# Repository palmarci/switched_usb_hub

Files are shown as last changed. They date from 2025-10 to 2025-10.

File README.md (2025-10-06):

# switched_usb_hub

a very cheap and basic switched usb 2.0 hub design based on:

- SL2.1A USB 4 way hub IC
- CH340C USB - serial adapter
- STM32F030F4Px microcontroller

the mcu talks with the PC over UART and toggles some FETs using GPIOs. nothing fancy.

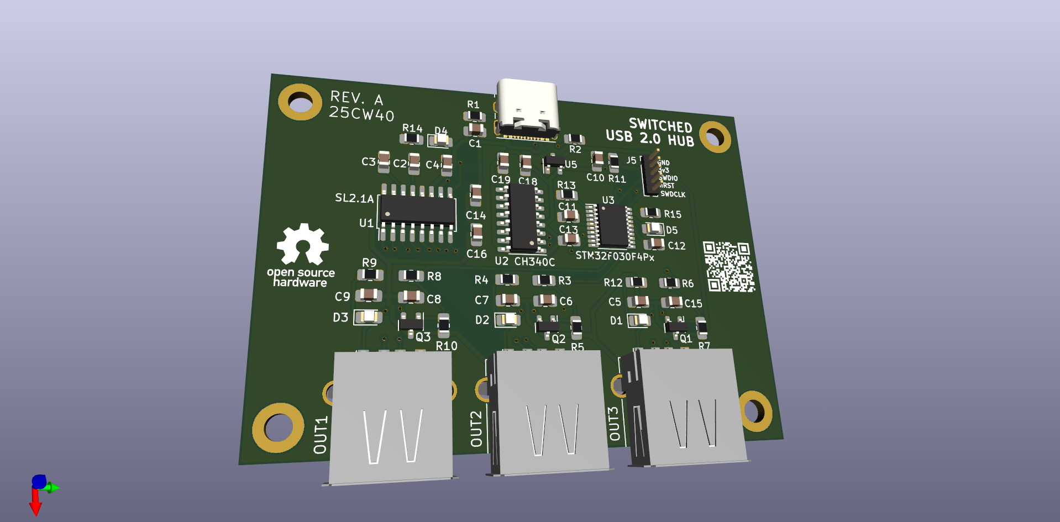
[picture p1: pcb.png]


original idea to use the SL2.1A: https://github.com/Hugoyhu/ZephyrHub/

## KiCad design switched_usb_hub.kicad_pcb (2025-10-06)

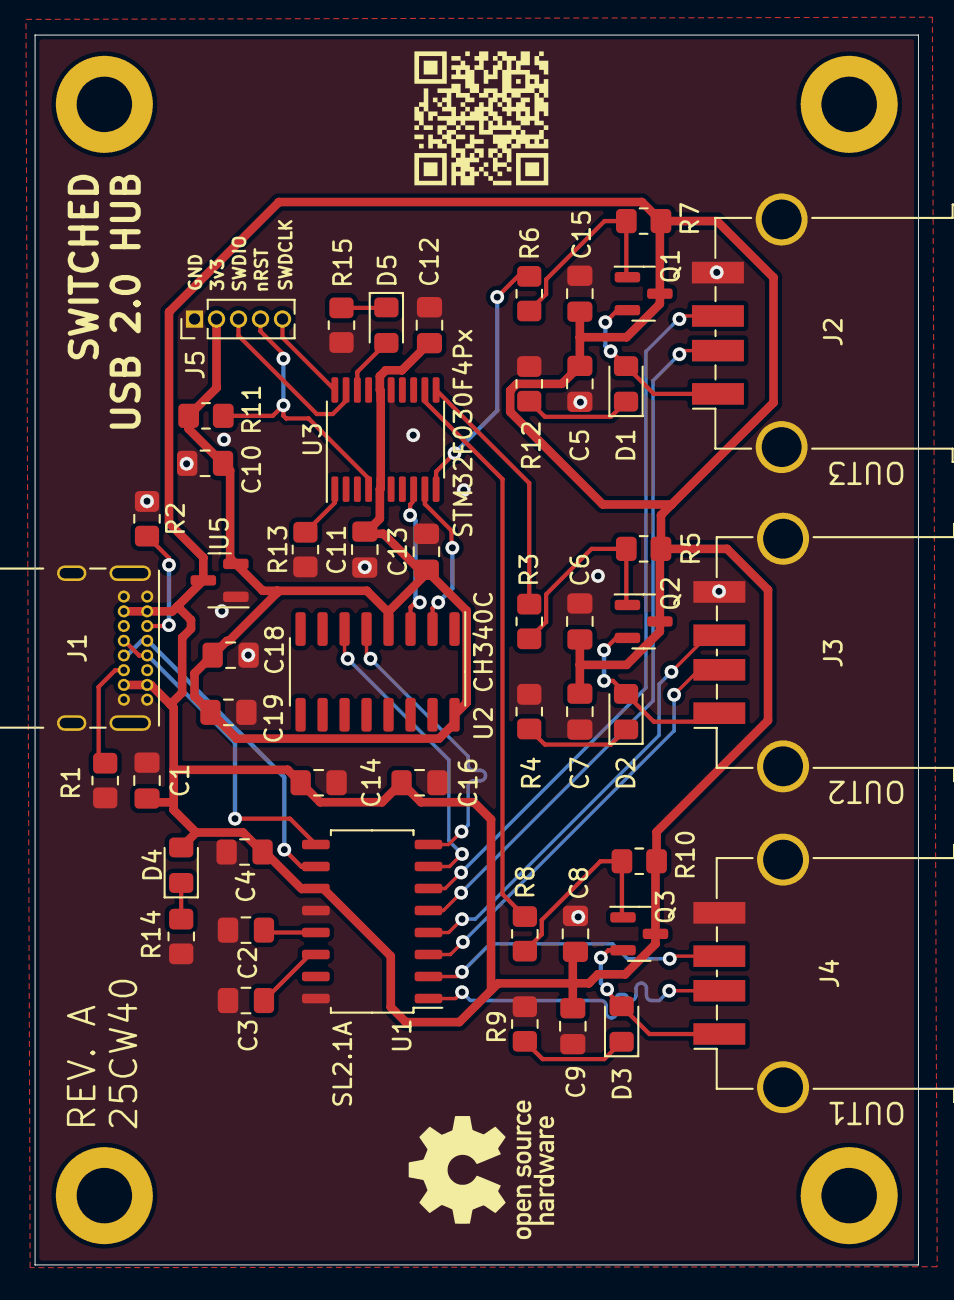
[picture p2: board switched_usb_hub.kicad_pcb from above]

Board: 2 copper layers, 51.0 x 71.0 mm, 50 parts (0 on the bottom side), 38 nets.

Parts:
C1, C2, C3, C12, C14, C18: 10uF; C_0805_2012Metric_Pad1.18x1.45mm_HandSolder
C4, C6, C8, C10, C15, C16, C19: 100nF; C_0805_2012Metric_Pad1.18x1.45mm_HandSolder
C5, C7, C9, C11: 1uF; C_0805_2012Metric_Pad1.18x1.45mm_HandSolder
C13: 0.1uF; C_0805_2012Metric_Pad1.18x1.45mm_HandSolder
D1, D2, D3: LED; LED_0805_2012Metric_Pad1.15x1.40mm_HandSolder
D4: 5V IN; LED_0805_2012Metric_Pad1.15x1.40mm_HandSolder
D5: TEST LED; LED_0805_2012Metric_Pad1.15x1.40mm_HandSolder
J1: USB_C_Receptacle_USB2.0; USB_C_Receptacle_GCT_USB4085
J2, J3, J4: USB_A; USB_A_TE_292303-7_Horizontal
J5: JTAG_CONN; PinHeader_1x05_P1.27mm_Vertical
Q1, Q2, Q3: IRLML6402; SOT-23
R1, R2: 5.1K; R_0805_2012Metric_Pad1.20x1.40mm_HandSolder
R3, R6, R8: 100; R_0805_2012Metric_Pad1.20x1.40mm_HandSolder
R4, R9, R12, R14, R15: 330R; R_0805_2012Metric_Pad1.20x1.40mm_HandSolder
R5, R7, R10, R11, R13: 10k; R_0805_2012Metric_Pad1.20x1.40mm_HandSolder
U1: SL2.1A; SOIC-16_4.55x10.3mm_P1.27mm
U2: CH340C; SOIC-16_3.9x9.9mm_P1.27mm
U3: STM32F030F4Px; TSSOP-20_4.4x6.5mm_P0.65mm
U5: MCP1700x-330xxTT; SOT-23

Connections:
+3V3: C10.2, C11.2, C12.1, C13.1, C18.1, C19.1, J5.2 (VCC), R11.1, U2.4 (V3), U2.16 (VCC), U3.5 (VDDA), U3.16 (VDD), U5.2 (VO)
+5V: C1.1, C4.2, C5.1, C6.1, C7.1, C8.1, C9.1, C14.1, C15.1, C16.1, D4.2 (A), J1.A4 (VBUS), J1.A9 (VBUS), J1.B4 (VBUS), J1.B9 (VBUS), Q1.3 (D), Q2.3 (D), Q3.3 (D), R5.1, R7.1, R10.1, U1.11 (VCC5V), U5.3 (VI)
/D1+: U1.8 (DP1), U2.5 (UD+)
/D1-: U1.7 (DM1), U2.6 (UD-)
/D2+: J2.3 (D+), U1.6 (DP2)
/D2-: J2.2 (D-), U1.5 (DM2)
/D3+: J3.3 (D+), U1.4 (DP3)
/D3-: J3.2 (D-), U1.3 (DM3)
/D4+: J4.3 (D+), U1.2 (DP4)
/D4-: J4.2 (D-), U1.1 (DM4)
/mcu_subsys/PSU_SW0: R6.2, U3.10 (PA4)
/mcu_subsys/PSU_SW1: R3.2, U3.11 (PA5)
/mcu_subsys/PSU_SW2: R8.2, U3.12 (PA6)
GND: C1.2, C2.2, C3.1, C4.1, C5.2, C6.2, C7.2, C8.2, C9.2, C10.1, C11.1, C12.2, C13.2, C14.2, C15.2, C16.2, C18.2, C19.2, J1.A1 (GND), J1.A12 (GND), J1.B1 (GND), J1.B12 (GND), J1.S1 (SHIELD), J2.4 (GND), J2.5 (Shield), J3.4 (GND), J3.5 (Shield), J4.4 (GND), J4.5 (Shield), J5.1 (GND), R1.2, R2.1, R4.2, R9.2, R12.2, R13.1, R14.2, R15.2, U1.12 (GND), U1.16 (XIN), U3.15 (VSS), U5.1 (GND)
unnamed: C2.1, U1.13 (VDD3)
unnamed: C3.2, U1.14 (VDD18)
unnamed: D1.1 (K), R12.1
unnamed: D1.2 (A), J2.1 (VBUS), Q1.2 (S)
unnamed: D2.1 (K), R4.1
unnamed: D2.2 (A), J3.1 (VBUS), Q2.2 (S)
unnamed: D3.1 (K), R9.1
unnamed: D3.2 (A), J4.1 (VBUS), Q3.2 (S)
unnamed: D4.1 (K), R14.1
unnamed: D5.1 (K), R15.1
unnamed: D5.2 (A), U3.18 (PA10)
unnamed: J1.A5 (CC1), R2.2
unnamed: J1.A6 (D+), J1.B6 (D+), U1.10 (UDP)
unnamed: J1.A7 (D-), J1.B7 (D-), U1.9 (UDM)
unnamed: J1.B5 (CC2), R1.1
unnamed: J5.3 (SWDIO), U3.19 (PA13)
unnamed: J5.4 (nRST), R11.2, U3.4 (NRST)
unnamed: J5.5 (SWDCLK), U3.20 (PA14)
unnamed: Q1.1 (G), R6.1, R7.2
unnamed: Q2.1 (G), R3.1, R5.2
unnamed: Q3.1 (G), R8.1, R10.2
unnamed: R13.2, U3.1 (BOOT0)
unnamed: U2.2 (TXD), U3.9 (PA3)
unnamed: U2.3 (RXD), U3.8 (PA2)

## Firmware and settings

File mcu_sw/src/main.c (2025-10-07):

#include "main.h"
#include <string.h>

static char rx_buf[RX_BUF_SIZE];
static uint8_t rx_index = 0;

UART_HandleTypeDef huart;
uint8_t rx_irq_byte;

const char *msg_ok = "OK\r\n";
const char *msg_err = "ERR\r\n";
const char *msg_fw = "Build " __DATE__ " " __TIME__  "\r\n";

#define UART_SEND(msg) HAL_UART_Transmit(&huart, (uint8_t *)msg, strlen(msg), HAL_MAX_DELAY);

uint16_t resolve_pin(int value) {
    
    // here the pinout can be remapped

    switch (value) {
        case 1:
            return PIN_PSU_SW0;
        case 2:
            return PIN_PSU_SW1;
        case 3:
            return PIN_PSU_SW2;

        default:
            return -1;
    }
}

void handle_psu_switch(int cmd_len, int state) {
    if (rx_buf[cmd_len] != '\0')
    {
        int val = atoi(&rx_buf[cmd_len]);
        uint16_t pin_mask = resolve_pin(val);

        if (pin_mask != -1) {
            HAL_GPIO_WritePin(GPIOA, pin_mask, state);
            UART_SEND(msg_ok);
        } else {
            UART_SEND(msg_err);
        }

    } else {
        UART_SEND(msg_err);
    }
    return;
}

void uart_process(uint8_t byte)
{
    if (byte == '\n' || byte == '\r')
    {
        rx_buf[rx_index] = '\0'; // terminate it string

        // parse commands
        if (strcmp(rx_buf, "VER") == 0)
        {
            UART_SEND(msg_fw);
        }
        else if (strncmp(rx_buf, "ON", 2) == 0)
        {
            handle_psu_switch(2, 1);
        }
        else if (strncmp(rx_buf, "OFF", 3) == 0)
        {
            handle_psu_switch(3, 0);
        }
        else
        {
            UART_SEND(msg_err);
        }

        rx_index = 0;
        memset(rx_buf, 0, RX_BUF_SIZE);
    }
    else
    {
        if (rx_index < RX_BUF_SIZE - 1)
        {
            rx_buf[rx_index++] = byte;
        }
        else
        {
            // Buffer overflow, reset
            rx_index = 0;
            memset(rx_buf, 0, RX_BUF_SIZE);
        }
    }
}

int main(void)
{
    HAL_Init();
    SystemClock_Config();
    MX_GPIO_Init();
    MX_USART1_UART_Init();

    // start uart interrupts
    HAL_UART_Receive_IT(&huart, &rx_irq_byte, 1);

    uint32_t last_tick = HAL_GetTick();

    while (1)
    {
     
        // Blink mode (toggle every 1000ms)
        if (HAL_GetTick() - last_tick >= 1000)
        {
            HAL_GPIO_TogglePin(GPIOA, PIN_TEST_LED);
            last_tick = HAL_GetTick();
        }
      
    }
}

void HAL_UART_RxCpltCallback(UART_HandleTypeDef *huart)
{
    if (huart->Instance == USART1)
    {
     
        uart_process(rx_irq_byte);

        // Restart RX interrupt
        HAL_UART_Receive_IT(huart, &rx_irq_byte, 1);
    }
}

void SystemClock_Config(void)
{
    // modified from https://github.com/BLavery/STM32F030F4P6-Arduino/blob/master/(stm32)/1.4.0/variants/DEMO_F030F4/variant.cpp

    RCC_OscInitTypeDef RCC_OscInitStruct;
    RCC_ClkInitTypeDef RCC_ClkInitStruct;

    /* Initializes the CPU, AHB and APB busses clocks */
    RCC_OscInitStruct.OscillatorType = RCC_OSCILLATORTYPE_HSI14; // | RCC_OSCILLATORTYPE_HSE;
    RCC_OscInitStruct.HSEState = RCC_HSE_OFF; // RCC_HSE_ON;
    RCC_OscInitStruct.HSI14State = RCC_HSI14_ON;
    RCC_OscInitStruct.HSI14CalibrationValue = RCC_HSI14CALIBRATION_DEFAULT; //16;
    RCC_OscInitStruct.PLL.PLLState = RCC_PLL_ON;
    RCC_OscInitStruct.PLL.PLLSource = RCC_PLLSOURCE_HSE;
    RCC_OscInitStruct.PLL.PLLMUL = RCC_PLL_MUL6;
    RCC_OscInitStruct.PLL.PREDIV = RCC_PREDIV_DIV1;

    if (HAL_RCC_OscConfig(&RCC_OscInitStruct) != HAL_OK)
    {
       __BKPT(0);
    }

    /* Initializes the CPU, AHB and APB busses clocks */
    RCC_ClkInitStruct.ClockType = RCC_CLOCKTYPE_HCLK | RCC_CLOCKTYPE_SYSCLK | RCC_CLOCKTYPE_PCLK1;
    RCC_ClkInitStruct.SYSCLKSource = RCC_SYSCLKSOURCE_PLLCLK;
    RCC_ClkInitStruct.AHBCLKDivider = RCC_SYSCLK_DIV1;
    RCC_ClkInitStruct.APB1CLKDivider = RCC_HCLK_DIV1;

    if (HAL_RCC_ClockConfig(&RCC_ClkInitStruct, FLASH_LATENCY_1) != HAL_OK)
    {
       __BKPT(0);
    }

    /* Configure the Systick interrupt time */
    HAL_SYSTICK_Config(HAL_RCC_GetHCLKFreq() / 1000);

    /* Configure the Systick */
    HAL_SYSTICK_CLKSourceConfig(SYSTICK_CLKSOURCE_HCLK);

    /* SysTick_IRQn interrupt configuration */
    HAL_NVIC_SetPriority(SysTick_IRQn, 0, 0);
}

void MX_GPIO_Init(void)
{
    __HAL_RCC_GPIOA_CLK_ENABLE();

    GPIO_InitTypeDef GPIO_InitStruct = {0};

    // test led
    GPIO_InitStruct.Pin = PIN_TEST_LED;
    GPIO_InitStruct.Mode = GPIO_MODE_OUTPUT_PP;
    GPIO_InitStruct.Pull = GPIO_PULLDOWN;
    GPIO_InitStruct.Speed = GPIO_SPEED_FREQ_LOW;
    HAL_GPIO_Init(GPIOA, &GPIO_InitStruct);

    // sw0
    GPIO_InitStruct.Pin = PIN_PSU_SW0;
    GPIO_InitStruct.Mode = GPIO_MODE_OUTPUT_PP;
    GPIO_InitStruct.Pull = GPIO_NOPULL;
    GPIO_InitStruct.Speed = GPIO_SPEED_FREQ_LOW;
    HAL_GPIO_Init(GPIOA, &GPIO_InitStruct);

    // sw1
    GPIO_InitStruct.Pin = PIN_PSU_SW1;
    GPIO_InitStruct.Mode = GPIO_MODE_OUTPUT_PP;
    GPIO_InitStruct.Pull = GPIO_NOPULL;
    GPIO_InitStruct.Speed = GPIO_SPEED_FREQ_LOW;
    HAL_GPIO_Init(GPIOA, &GPIO_InitStruct);

    // sw2
    GPIO_InitStruct.Pin = PIN_PSU_SW2;
    GPIO_InitStruct.Mode = GPIO_MODE_OUTPUT_PP;
    GPIO_InitStruct.Pull = GPIO_NOPULL;
    GPIO_InitStruct.Speed = GPIO_SPEED_FREQ_LOW;
    HAL_GPIO_Init(GPIOA, &GPIO_InitStruct);

    return;
}

void MX_USART1_UART_Init(void)
{
    __HAL_RCC_USART1_CLK_ENABLE();
    __HAL_RCC_GPIOA_CLK_ENABLE(); // already performed in MX_GPIO_Init()

    GPIO_InitTypeDef GPIO_InitStruct = {0};

    GPIO_InitStruct.Pin = PIN_UART_TX;
    GPIO_InitStruct.Mode = GPIO_MODE_AF_PP;
    GPIO_InitStruct.Pull = GPIO_NOPULL;
    GPIO_InitStruct.Speed = GPIO_SPEED_FREQ_HIGH;
    GPIO_InitStruct.Alternate = GPIO_AF1_USART1;
    HAL_GPIO_Init(GPIOA, &GPIO_InitStruct);

    GPIO_InitStruct.Pin = PIN_UART_RX;
    GPIO_InitStruct.Mode = GPIO_MODE_INPUT;
    GPIO_InitStruct.Pull = GPIO_NOPULL;
    GPIO_InitStruct.Speed = GPIO_SPEED_FREQ_HIGH;
    GPIO_InitStruct.Alternate = GPIO_AF1_USART1;
    HAL_GPIO_Init(GPIOA, &GPIO_InitStruct);

    huart.Instance = USART1;
    huart.Init.BaudRate = 115200;
    huart.Init.WordLength = UART_WORDLENGTH_8B;
    huart.Init.StopBits = UART_STOPBITS_1;
    huart.Init.Parity = UART_PARITY_NONE;
    huart.Init.Mode = UART_MODE_TX_RX;
    huart.Init.HwFlowCtl = UART_HWCONTROL_NONE;
    huart.Init.OverSampling = UART_OVERSAMPLING_16;

    HAL_UART_Init(&huart);

    return;
}

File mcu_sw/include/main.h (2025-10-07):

#ifndef MAIN_H
#define MAIN_H

#include "stm32f030x6.h"
#include <stm32f0xx.h>
#include <stm32f0xx_hal.h>

#define PIN_TEST_LED    GPIO_PIN_10     // PA10
#define PIN_PSU_SW0     GPIO_PIN_4      // PA4
#define PIN_PSU_SW1     GPIO_PIN_5      // PA5
#define PIN_PSU_SW2     GPIO_PIN_6      // PA6
#define PIN_UART_TX     GPIO_PIN_2      // PA2
#define PIN_UART_RX     GPIO_PIN_3      // PA3

#define RX_BUF_SIZE     32

void SystemClock_Config(void);
void MX_GPIO_Init(void);
void MX_USART1_UART_Init(void);

extern int atoi (const char * str);

#endif // MAIN_H

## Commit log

2025-10-06 adding files
    [mcu_subsys.kicad_sch, regulator.kicad_sch, switched_usb_hub.kicad_pcb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]
2025-10-06 adding rev A hopefully final files
    [mcu_subsys.kicad_sch, switched_usb_hub.kicad_pcb]
2025-10-07 wrote (untested) firmware
    [mcu_subsys.kicad_sch]
2025-10-07 oops wrong uart pin config
    [main.c]
